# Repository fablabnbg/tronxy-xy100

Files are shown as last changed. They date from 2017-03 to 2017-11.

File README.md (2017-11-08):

# TRONXY-xy100 STARTT
Working with an inexpensive 3D printer. Other names: STARTT (by imakr.com) -- An almost identical but larger version is ANET A8.

The designs found here are also published at http://www.thingiverse.com/thing:2174029

External references:
* https://www.facebook.com/groups/officialSTARTT3dprintergroup/
* https://www.imakr.com/eu/en/forum/topic/108-custom-made-cura-for-startt-updated-24-july-2017#post-655
* https://github.com/prusa3d/Original-Prusa-i3/tree/MK2/Printed-Parts/scad
* https://www.imakr.com/en/content/169-startt-3d-printer-support
* http://www.ebay.de/itm/MINI-Tronxy-3d-DIY-Printer-Precision-Reprap-Prusa-8GB-SD-Card-120-140-130mm/192107538708
* http://www.gearbest.com/3d-printers-3d-printer-kits/pp_361425.html
* https://github.com/erikkallen/Marlin_tronxy
* http://www.thingiverse.com/thing:1683070 Anet A8 Improved X-belt Tensioner
* https://www.thingiverse.com/thing:2267392 TronXY XY-100 Startt iMakr - Fan Shroud Duct
* https://www.imakr.com/eu/en/forum/topic/32-startt-why-no-topics-or-usa-forums/page-2#post-65

Electronics:

MKS MELZI control board V5_2.0

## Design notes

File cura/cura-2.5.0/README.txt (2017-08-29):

Cura 2.5.0 loads the settings from cura 2.4.0 hooray.

But they introduced a new issue: Starting cura with stl files on the command
line only works when a full path is given. See the cura.sh script for a
workaround.

The x-endstop is defined to be at -10mm in the Firmware.
With the larger bed, we can gain another 10mm in x, by redefining it to be at 0mm

; directly after xy home, do:
G92 X0

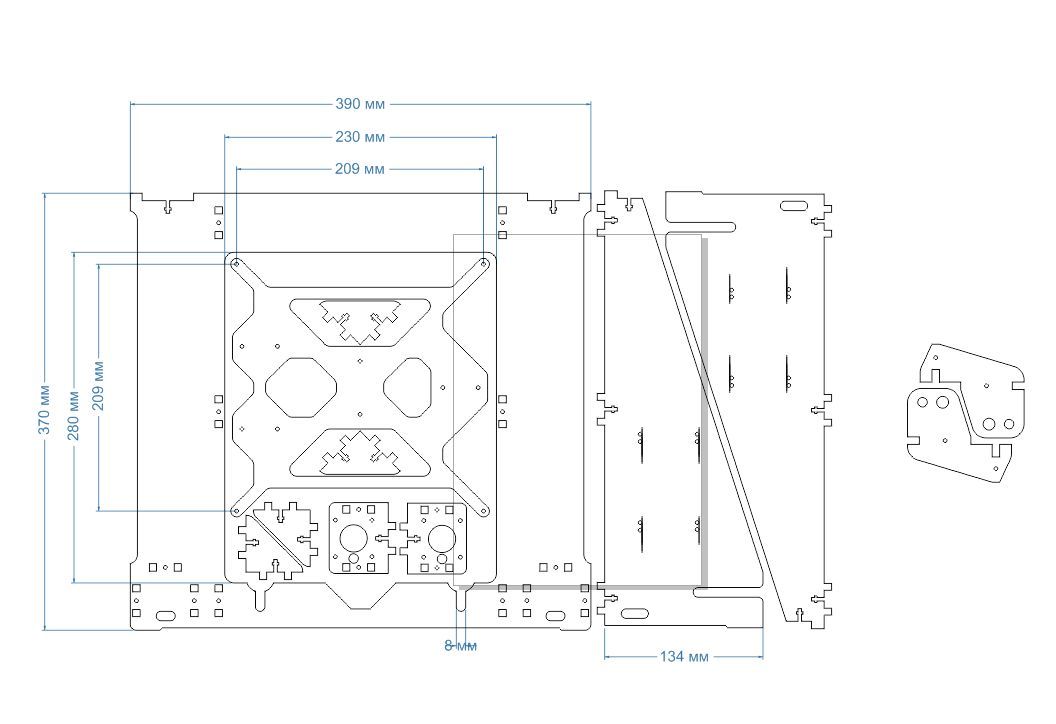
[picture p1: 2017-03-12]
doc/frame-drawing-s-l1600.jpg

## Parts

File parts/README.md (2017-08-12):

parts found elsewhere
=====================

* X-axis idler with belt tensioning http://www.thingiverse.com/thing:2205270
* TronXY XY-100 Startt iMakr - Fan Shroud Duct https://www.thingiverse.com/thing:2267392

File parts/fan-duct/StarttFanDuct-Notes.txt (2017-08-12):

TronXY XY-100 and iMakr Startt - Fan Shroud and Duct
Created On: 2017-04-23
Created By: Mark Dickson

This part is licensed under the Creative Commons - Attribution - Non-Commercial - Share-Alike (CC BY-NC-SA) license.  
You may do whatever you want with this file and design for your own personal use, but I drafted this up for the hobbyist community and wish to keep it "open-source."  
If you remix and re-release any part of this file, please ensure it is licensed under the same conditions.

This part is also available on Thingiverse here: https://www.thingiverse.com/thing:2267392

Description from Thingiverse:
2017-04-24 - Ran the part through NetFabb to fix some minor issues.

For those of you making the Startt printer from iMakr or the TronXY XY-100, you probably found that the 3D printed parts that came with your kit were not printed with the most care. Some other people have designed and posted various replacement parts that you can print yourself, but no one seemed to have posted the fan shroud, even though it was requested in the forums.

So here is my version of the fan shroud that came with my Startt kit from iMakr.

You can also find a number of redesigned parts here:
https://www.thingiverse.com/thing:2174029/

In addition to the Left and Right side X-Axis Gantry ends available here:
https://www.imakr.com/us/en/forum/topic/42-startt-3d-printed-part-files

If you have any feedback or suggestions, please let me know.

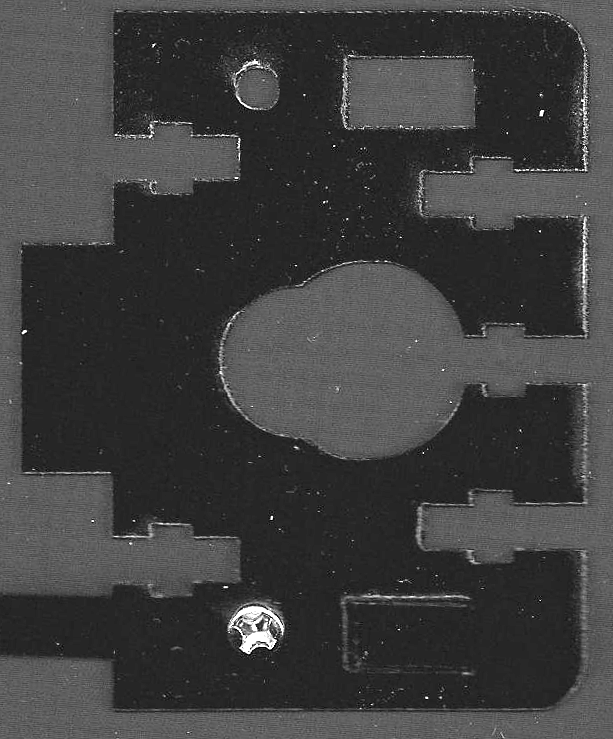
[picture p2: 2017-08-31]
parts/orig/scan300dpi/png/startt0008.png

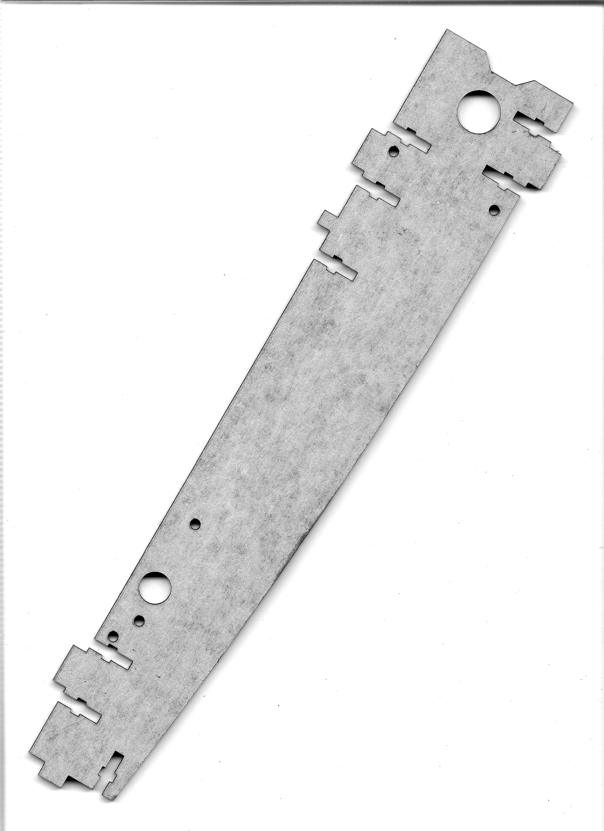
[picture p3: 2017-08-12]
parts/orig/scan300dpi/png/startt0002.png

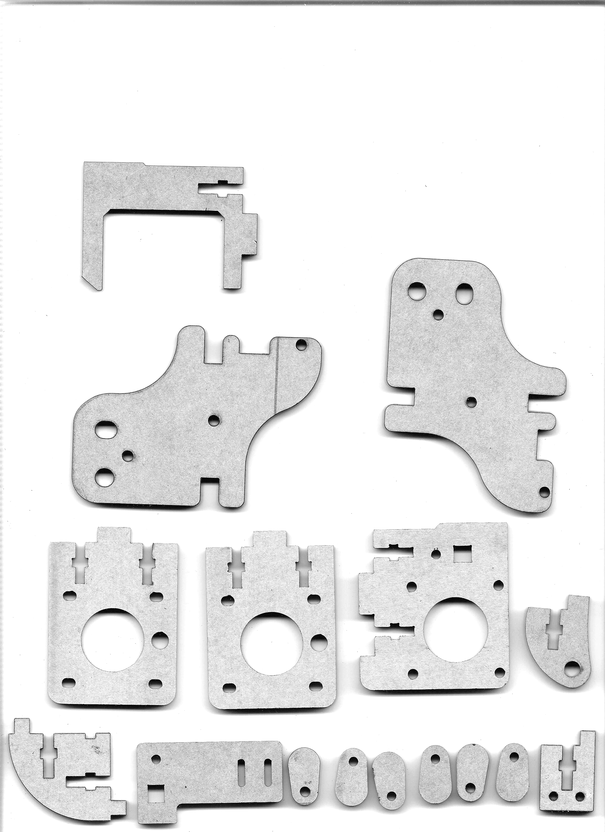
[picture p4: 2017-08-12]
parts/orig/scan300dpi/png/startt0004.png

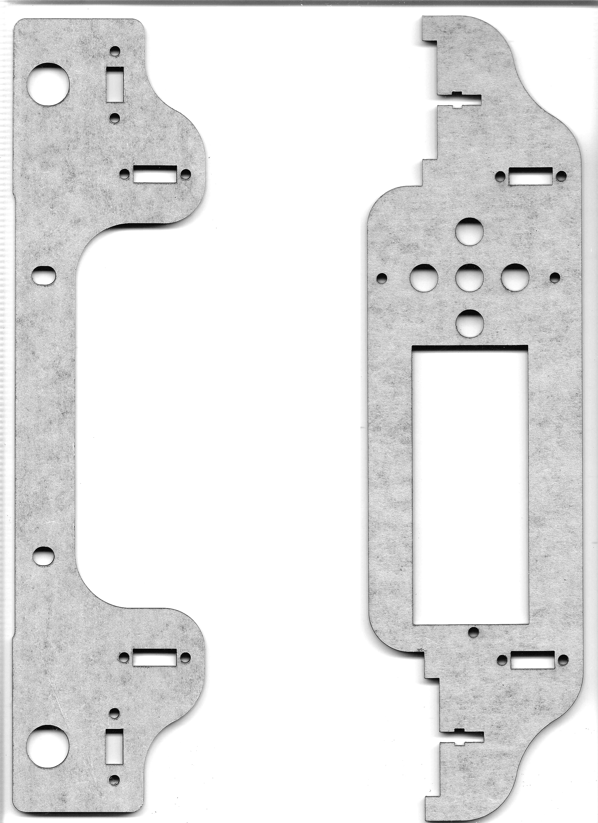
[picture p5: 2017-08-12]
parts/orig/scan300dpi/png/startt0003.png

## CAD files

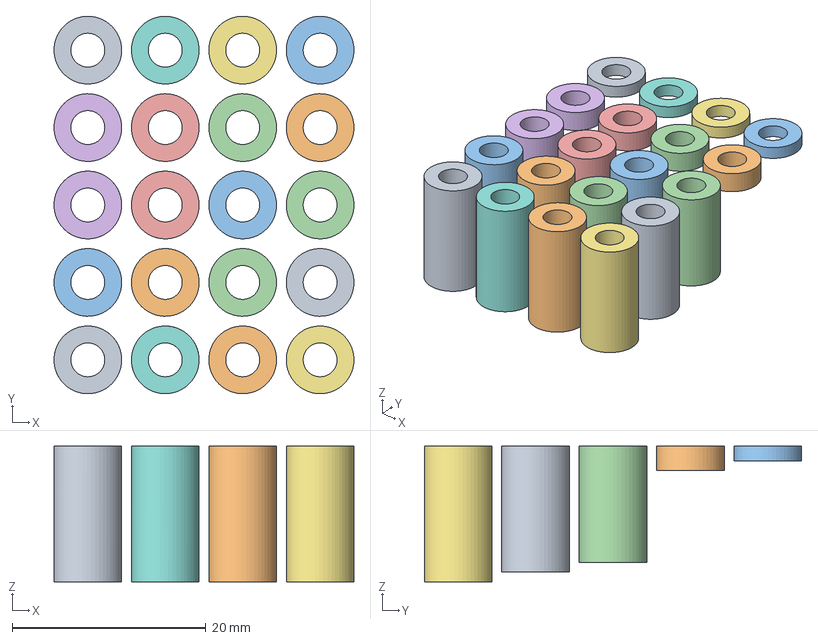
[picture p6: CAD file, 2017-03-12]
parts/display-spacer/display-spacer.fcstd
31.0 x 39.0 x 14.0 mm
13mm
13mm-4mm
13mm-4mm001
12mm
12mm-4mm
12mm-4mm001
14mm
14mm-4mm
14mm-4mm001
2.5mm
1.5mm
2.5mm001
2.5mm002
2.5mm003
1.5mm001
1.5mm002
1.5mm003
14mm001
12mm001
13mm001

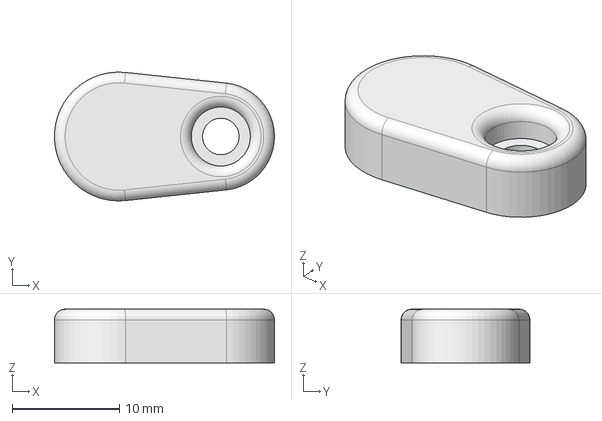
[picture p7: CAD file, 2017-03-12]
parts/end-cap/end-cap.fcstd
20.5 x 12.0 x 5.00 mm

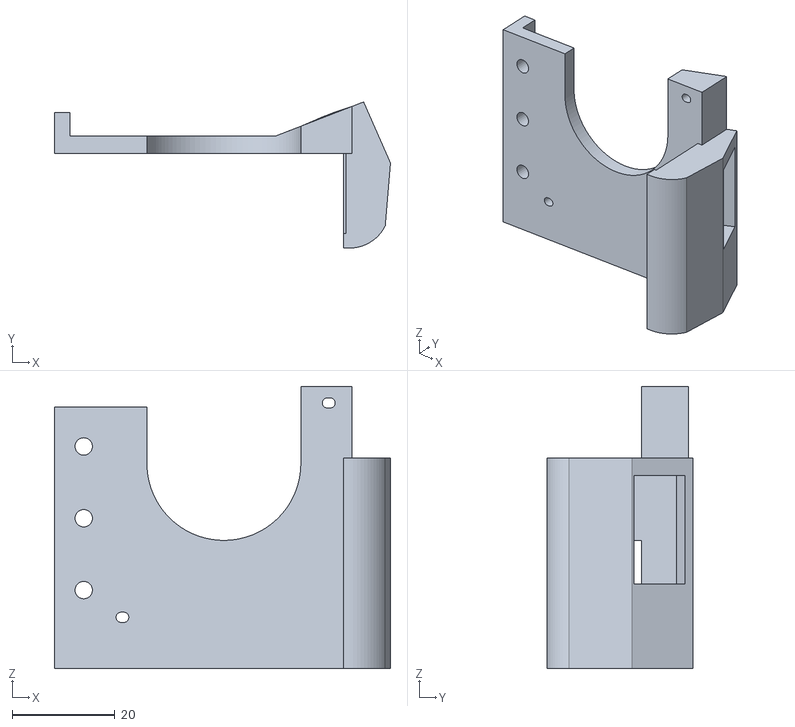
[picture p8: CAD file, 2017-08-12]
parts/fan-duct/StarttFanDuct.stl
65.5 x 28.5 x 55.0

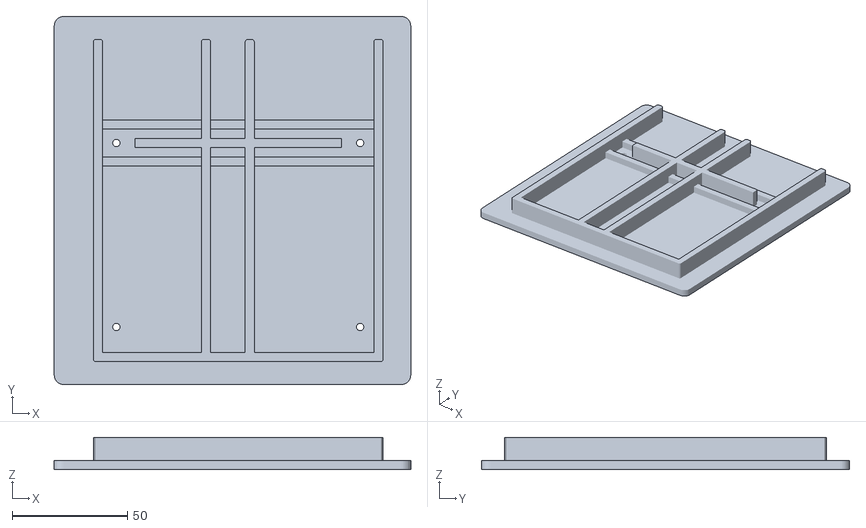
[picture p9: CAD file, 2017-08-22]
parts/plate/tronxy-plate-fc.stl
155.0 x 160.0 x 14.0

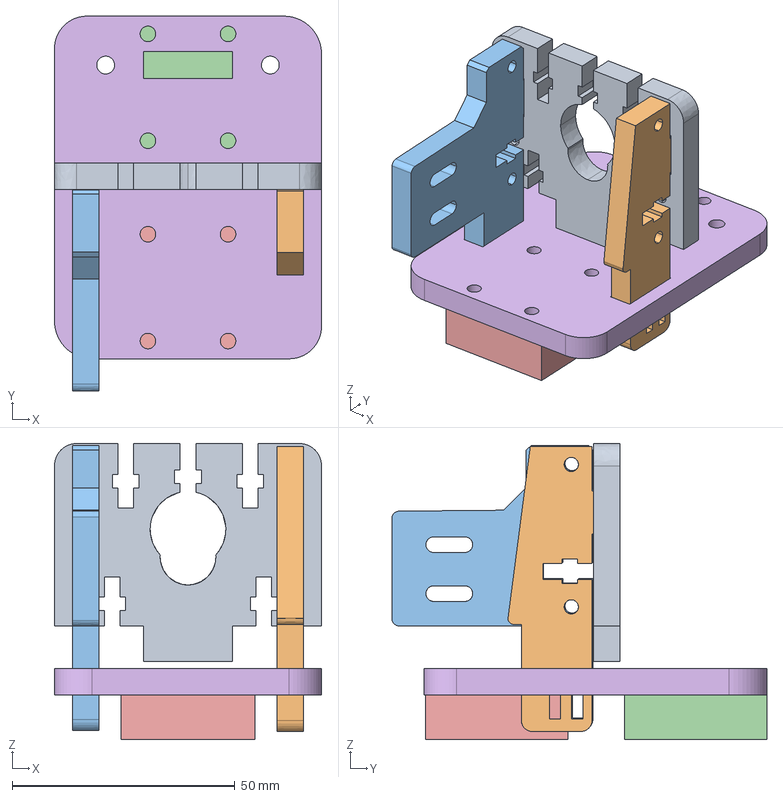
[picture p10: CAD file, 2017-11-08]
parts/print-head/head.fcstd
60.0 x 84.2 x 66.5 mm
top
left
right
bearingT
bearingB
Back

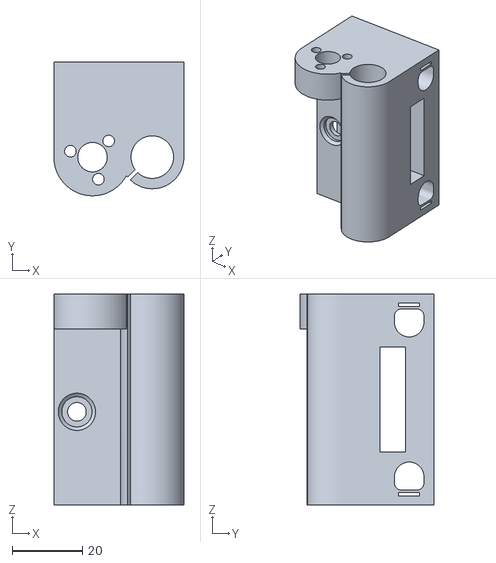
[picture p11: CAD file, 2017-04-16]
parts/Right.stl
36.9 x 38.0 x 60.0

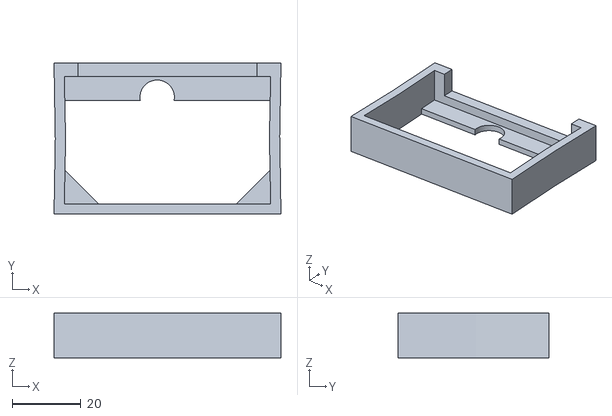
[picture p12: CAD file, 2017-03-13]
parts/x-gantry-far-end-cover/x-gantry-far-end-cover.stl
66.0 x 44.0 x 13.0

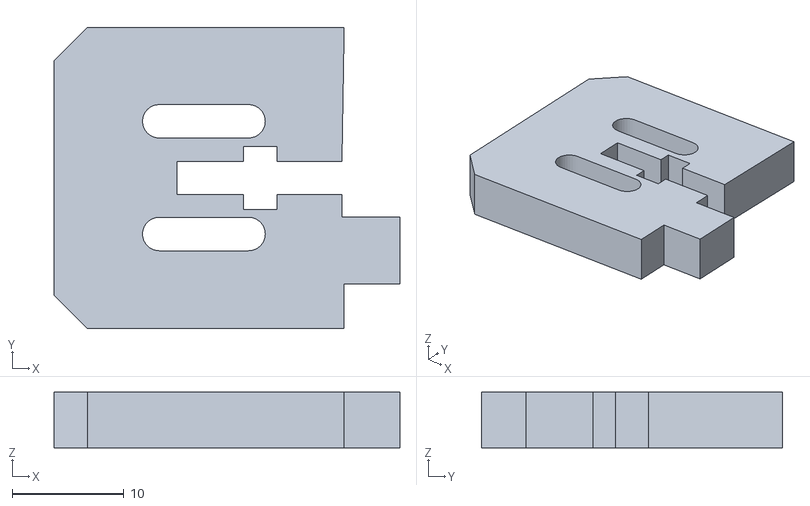
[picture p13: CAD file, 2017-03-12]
parts/y-endstop-mount/y-endstop-mount.stl
31.0 x 27.0 x 5.00

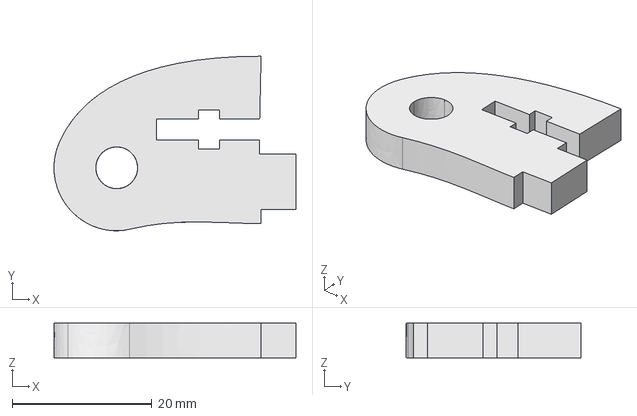
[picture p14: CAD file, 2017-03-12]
parts/y-idler-mount/y-idler-mount.fcstd
34.7 x 25.0 x 5.00 mm

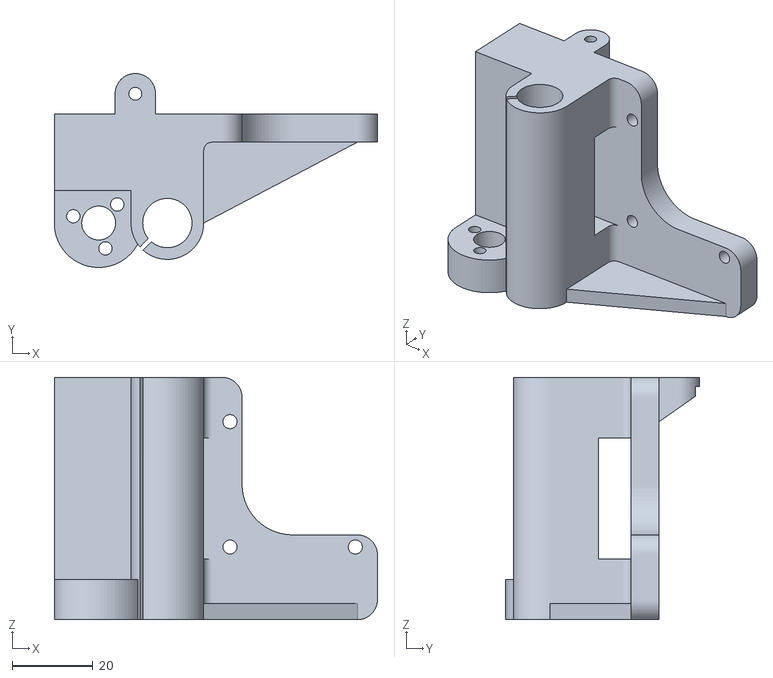
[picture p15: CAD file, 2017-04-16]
parts/Left.stl
79.9 x 48.0 x 60.0

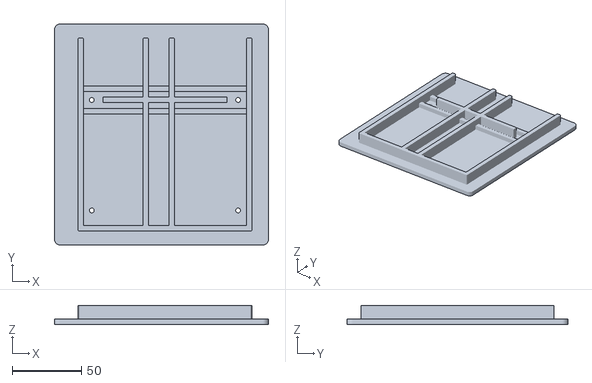
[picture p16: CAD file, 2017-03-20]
parts/plate/tronxy-plate.stl
155.0 x 160.0 x 14.0

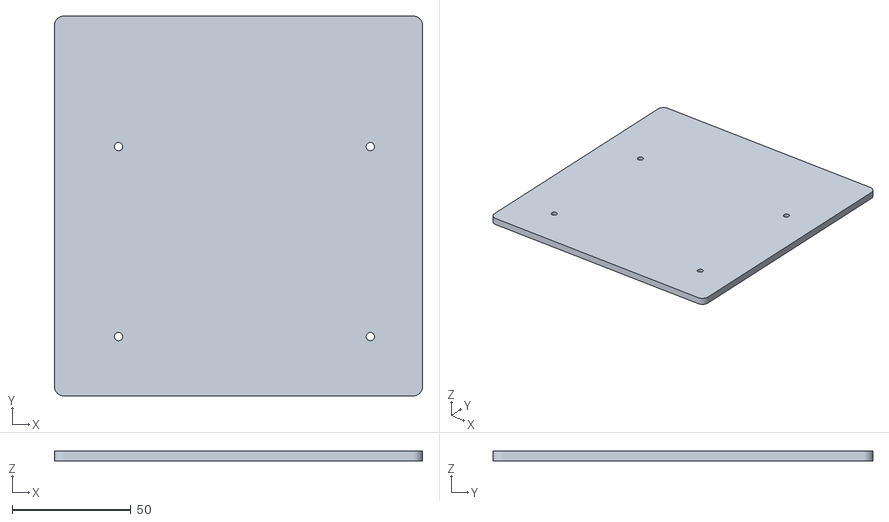
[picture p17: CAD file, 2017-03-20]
parts/plate/tronxy-plate_2.stl
155.0 x 160.0 x 4.00

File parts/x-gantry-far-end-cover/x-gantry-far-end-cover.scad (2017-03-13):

// Module names are of the form poly_<inkscape-path-id>().  As a result,
// you can associate a polygon in this OpenSCAD program with the corresponding
// SVG element in the Inkscape document by looking for the XML element with
// the attribute id="inkscape-path-id".

// fudge value is used to ensure that subtracted solids are a tad taller
// in the z dimension than the polygon being subtracted from.  This helps
// keep the resulting .stl file manifold.
fudge = 0.1;

module poly_rect4149_5mm(h)
{
  scale([25.4/90, -25.4/90, 1]) union()
  {
    linear_extrude(height=h)
      polygon([[-102.756266,-77.952540],[99.212247,-77.952540],[99.212247,-63.779312],[-102.756266,-63.779312]]);
  }
}

module poly_path4143_13mm(h)
{
  scale([25.4/90, -25.4/90, 1]) union()
  {
    linear_extrude(height=h)
      polygon([[-116.928714,-77.951426],[-115.619021,0.247187],[-116.928714,77.952540],[116.928714,77.952540],[115.619024,-2.372193],[116.928714,-77.951426],[92.125983,-77.951426],[92.125983,-63.779546],[106.297854,-63.779546],[104.988164,-1.389933],[106.297854,67.323629],[-106.299808,67.323629],[-104.990115,0.902037],[-106.299808,-63.779546],[-92.125979,-63.779546],[-92.125979,-77.951426]]);
  }
}

module poly_rect3338_2mm(h)
{
  scale([25.4/90, -25.4/90, 1]) union()
  {
    linear_extrude(height=h)
      polygon([[-113.385407,-77.951426],[-113.385407,-38.976815],[-106.299808,-38.976815],[-27.969722,-38.976815],[-28.247493,-40.738797],[-28.346682,-42.519785],[-28.255237,-44.331237],[-27.986785,-46.090362],[-27.550230,-47.788255],[-26.954480,-49.416010],[-26.208438,-50.964722],[-25.321012,-52.425483],[-24.301108,-53.789389],[-23.157630,-55.047534],[-21.899485,-56.191012],[-20.535579,-57.210917],[-19.074818,-58.098342],[-17.526106,-58.844384],[-15.898351,-59.440134],[-14.200458,-59.876689],[-12.441333,-60.145141],[-10.629881,-60.236586],[-8.818429,-60.145141],[-7.059304,-59.876689],[-5.361411,-59.440134],[-3.733655,-58.844384],[-2.184944,-58.098342],[-0.724183,-57.210917],[0.639724,-56.191012],[1.897868,-55.047534],[3.041346,-53.789389],[4.061251,-52.425483],[4.948676,-50.964722],[5.694718,-49.416010],[6.290468,-47.788255],[6.727023,-46.090362],[6.995475,-44.331237],[7.086920,-42.519785],[6.996476,-40.739247],[6.727540,-38.976815],[106.299814,-38.976815],[113.385404,-38.976815],[113.385404,-77.951426]]);
    linear_extrude(height=h)
      polygon([[-113.385407,31.889698],[-113.385407,74.409229],[-70.865874,74.409229],[-70.865874,67.323629],[-106.299808,31.889698]]);
    linear_extrude(height=h)
      polygon([[106.299814,31.889698],[70.865872,67.323629],[70.865872,74.409229],[113.385404,74.409229],[113.385404,31.889698]]);
  }
}

module yendstopmount(h)
{

poly_rect4149_5mm(5);
poly_path4143_13mm(13);
poly_rect3338_2mm(2);
}

yendstopmount(5);

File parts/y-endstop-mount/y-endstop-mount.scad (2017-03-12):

// Module names are of the form poly_<inkscape-path-id>().  As a result,
// you can associate a polygon in this OpenSCAD program with the corresponding
// SVG element in the Inkscape document by looking for the XML element with
// the attribute id="inkscape-path-id".

// fudge value is used to ensure that subtracted solids are a tad taller
// in the z dimension than the polygon being subtracted from.  This helps
// keep the resulting .stl file manifold.
fudge = 0.1;

module poly_yendstopmount_5mm(h)
{
  scale([25.4/90, -25.4/90, 1]) union()
  {
    difference()
    {
       linear_extrude(height=h)
         polygon([[-44.292335,-47.834962],[-54.921241,-37.204101],[-54.921241,37.204101],[-44.292335,47.834962],[37.204440,47.834962],[37.204440,33.661141],[54.921241,33.661141],[54.921241,12.401370],[36.495450,12.401370],[36.495450,5.315430],[15.944670,5.315430],[15.944670,9.920900],[5.313809,9.920900],[5.313809,5.315430],[-15.945952,5.315430],[-15.945952,-5.315430],[5.313809,-5.315430],[5.313809,-9.920900],[15.944670,-9.920900],[15.944670,-5.315430],[36.495450,-5.315430],[37.204440,-47.834962]]);
       translate([0, 0, -fudge])
         linear_extrude(height=h+2*fudge)
           polygon([[-21.506502,-23.317711],[-21.504502,-23.317711],[6.841209,-23.317711],[7.912337,-23.209753],[8.909951,-22.900120],[9.812692,-22.410170],[10.599198,-21.761263],[11.248109,-20.974759],[11.738063,-20.072015],[12.047700,-19.074393],[12.155659,-18.003251],[12.047691,-16.933625],[11.738031,-15.939664],[11.248048,-15.041438],[10.599112,-14.259017],[9.812591,-13.612472],[8.909854,-13.121874],[7.912271,-12.807293],[6.841209,-12.688800],[-21.504502,-12.688800],[-21.506502,-12.688800],[-22.577369,-12.797074],[-23.574862,-13.106913],[-24.477587,-13.596967],[-25.264152,-14.245888],[-25.913164,-15.032326],[-26.403230,-15.934932],[-26.712958,-16.932357],[-26.820954,-18.003251],[-26.712958,-19.074160],[-26.403230,-20.071592],[-25.913164,-20.974201],[-25.264152,-21.760637],[-24.477587,-22.409554],[-23.574862,-22.899604],[-22.577369,-23.209439],[-21.506502,-23.317711]]);
       translate([0, 0, -fudge])
         linear_extrude(height=h+2*fudge)
           polygon([[-21.506502,12.468730],[-21.504502,12.468730],[6.841209,12.468730],[7.912337,12.576689],[8.909951,12.886325],[9.812692,13.376279],[10.599198,14.025188],[11.248109,14.811693],[11.738063,15.714434],[12.047700,16.712050],[12.155659,17.783181],[12.047700,18.854395],[11.738063,19.852232],[11.248109,20.755285],[10.599198,21.542148],[9.812692,22.191416],[8.909951,22.681681],[7.912337,22.991538],[6.841209,23.099581],[-21.504502,23.099581],[-21.506502,23.099581],[-22.577368,22.991224],[-23.574860,22.681165],[-24.477585,22.190800],[-25.264150,21.541522],[-25.913162,20.754727],[-26.403229,19.851808],[-26.712957,18.854162],[-26.820954,17.783181],[-26.712957,16.712272],[-26.403229,15.714839],[-25.913162,14.812231],[-25.264150,14.025796],[-24.477585,13.376880],[-23.574860,12.886832],[-22.577368,12.576999],[-21.506502,12.468730]]);
    }
  }
}

module yendstopmount(h)
{

poly_yendstopmount_5mm(5);
}

yendstopmount(5);

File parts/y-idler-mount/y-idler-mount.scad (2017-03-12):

// Module names are of the form poly_<inkscape-path-id>().  As a result,
// you can associate a polygon in this OpenSCAD program with the corresponding
// SVG element in the Inkscape document by looking for the XML element with
// the attribute id="inkscape-path-id".

// fudge value is used to ensure that subtracted solids are a tad taller
// in the z dimension than the polygon being subtracted from.  This helps
// keep the resulting .stl file manifold.
fudge = 0.1;

module poly_path4149(h)
{
  scale([25.4/90, -25.4/90, 1]) union()
  {
    difference()
    {
       linear_extrude(height=h)
         polygon([[-14.980675,9.170943],[-14.125093,10.087945],[-13.164453,10.872662],[-12.115798,11.516096],[-10.996169,12.009246],[-9.822610,12.343113],[-8.612164,12.508700],[-7.381873,12.497006],[-6.148779,12.299033],[-3.555842,11.771471],[-1.130938,11.448630],[3.365558,11.251439],[12.000853,11.491303],[12.000853,9.491303],[17.000852,9.491303],[17.000852,1.491303],[12.000853,1.491303],[12.000853,-0.508697],[6.000853,-0.508697],[6.000853,0.491303],[3.000853,0.491303],[3.000853,-0.508697],[-1.999148,-0.508697],[-1.999148,-3.508697],[3.000853,-3.508697],[3.000853,-4.508697],[6.000853,-4.508697],[6.000853,-3.508697],[12.000853,-3.508697],[12.000853,-12.508700],[6.039284,-12.279476],[0.871483,-11.612112],[-3.552188,-10.537067],[-7.281372,-9.084800],[-8.901043,-8.226728],[-10.365707,-7.285772],[-11.681570,-6.265741],[-12.854835,-5.170443],[-14.798396,-2.769271],[-16.246030,-0.112717],[-16.667302,1.064963],[-16.918087,2.272144],[-17.000852,3.491613],[-16.918062,4.706162],[-16.672183,5.898579],[-16.265682,7.051656],[-15.701024,8.148180],[-14.980675,9.170943]]);
       translate([0, 0, -fudge])
         linear_extrude(height=h+2*fudge)
           polygon([[-5.499148,3.491303],[-5.695610,4.464415],[-6.231381,5.259069],[-7.026035,5.794840],[-7.999148,5.991303],[-8.972261,5.794840],[-9.766915,5.259069],[-10.302686,4.464415],[-10.499148,3.491303],[-10.302686,2.518191],[-9.766915,1.723537],[-8.972261,1.187766],[-7.999148,0.991303],[-7.026035,1.187766],[-6.231381,1.723537],[-5.695610,2.518191],[-5.499148,3.491303]]);
    }
  }
}

poly_path4149(5);

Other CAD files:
parts/plate/plate.fcstd
parts/display-spacer/display-spacer.stl
parts/end-cap/end-cap.stl
parts/fan-duct/StarttFanDuct.skp
parts/y-idler-mount/y-idler-mount.stl

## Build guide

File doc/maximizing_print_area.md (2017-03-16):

Maximizing the Print Area
=========================

The movement in X and Y direction does not exactly bring the nozzle to the edges of the print plate.
The movement in Z direction is limited.

To address this, several parts were redesigned. Most part are 2D objects to be cut out of 5mm acrylic or to be 3D-printed. These parts are constructed with inkscape and are contained in parts/parts.svg -- exported *.scad and *.stl files from these parts are found in corresponding subdirectories.
Other parts (e.g. end-caps) are created as true 3D-objects with freeCAD. Their source are *.fcstd files located in subdirectories of the parts folder.

With the modfications described here, the print area can be extended from 120mm x 140mm to 155mm x 160mm

Optimizing build height
-----------------------
1. The build plate can be lowered to ca 7mm above the Y-table. Adjustable by 
tightening the 4 thumb screws under the table. The available Z-end stop 
adjustment can compensate for that.

2. Upper movement is blocked by the print head hitting the buttons of the display already at a height of 65mm. We re-mount the display, so that the buttons protrude only 1mm through the top plate, and the display itself is flush. parts/display-spacer.stl has a range of spacers, long and short in some variation.

3. The remaining obstacles are
* Two rounded acrylic pieces colliding 5mm before the brass nuts would hit the top cover.
* The mount of the print head wastes ca 20mm height. The nozzle height should not be much lower than the linear bearings.

Optimizing the front edge
-------------------------
In Y direction, the plate cannot move far enough inwards, so that the nozzle
reaches the front edge.

There are several obstacles, that prevent sufficient movement.

1. The Y endstop mount is not adjustable. It stops the movement early.
A redesigned y-endstop-mount.stl allows adjustment.

2. The long 20mm screws from the end-caps of the rods protrude ca 10mm beyond the nuts. This collides with the table.
Redsigned end-caps with only 2mm thickness under the screw head allow for use of 10mm screws that do not protrude at all.
  
3. The Y motor mount has an upper corner that collides with the table.
The corner needs to be cut away with saw and file. (I am too lazy to recreate that piece right now.)

4. The y motor connector is on the top according to the assembly guide. This collides with the print plate. Rotate the motor 180 deg, there is enough space on the bottom to accomodate connector and cable.

With these adjustments, the nozzle reaches the fromt of the build plate just
before the table hits the screws in the back wall. No further optimization
possible there. Please make sure all cables are zip tied away from the
collision area.

Optimizing the rear edge
------------------------

The programmed travel is longer than the physical travel. Pausing a print causes the table to move fully outward and hitting the physical limits. The y-position is lost, resuming the print is not possible.

1. When the table moves forward it collides with the large washers of the idler.
A redesigned parts/y-idler-mount lowers the idler by 1.5mm so that it fits 
under the table. A belt tensioning mechanism could also be added here. Easiest is an oblong hole for mounting the roller bearing.

The belt is attached to the table at a position reached by the idler. This prevents further movement. The rails have 8 mm more travel, but the nozzle is already 4 mm beyond the rear edge of the plate.

Optimizing left edge
--------------------

The x-limit switch protrudes from the print head. The switch should trigger just 1mm before the print head hits the block.

Optimizing the right edge
-------------------------

There is ca 20mm unused travel on the right hand side. We need smaller roller bearings for the x-idler, so that the belt moves more horizontal. It should have approximately the same diameter as the pulley. 
The programmed travel is shorter than the physical travel.

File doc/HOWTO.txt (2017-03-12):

					jw, Sa 11. Mär 13:36:00 CET 2017
					jw, Fr 10. Mär 20:47:28 CET 2017
do the assembly
===============
firefox https://www.imakr.com/en/content/169-startt-3d-printer-support
# open Assembling_Guide_English.pdf
#
# Additional resources:
# - Reserve table space of ca. 0.8m x 1.4m
# - Have a plate for spreading out the contents of the pack of screws and nuts. 
# - Have a second small plate for collecting the screws and nuts for each step.
# - A tipped knive, safer if blunt.
# - pointed pair of pliers for holding nuts. Especially also the ring on the power jack.

-> The acrylic parts are all covered on both sides with adhesive paper.
   This needs to be peeled off. A tipped knive is very helpful to get moving at one corner.
   The small flat screwdriver also works.
 
-> Step 2: There are two switches with short leads, one with long leads. Used a short one.

-> Step 4: There may be some acrylic dirt attached to the inside of the Motor
   Holder. Scrape this off with a knive.
   Do not tighten the 'Motor Holder' without assembling the motor
   There should be a hole in the 'Motor Holder', so that the screw beneath can be reached.

-> Step 6: In Parts required: 'Smooth Rod x2' should say 'Smooth Rod (shortest) x2' 
   This is only mentioned later, causing a needless moment of confusion.
   
-> Step 7: Orient the motor connectors under the longer side of the acrylic pieces.

-> Step 8: In Parts Required: Left stepper motor should mention '(A)', right motor '(B)'

-> Step 9: Use the limit switch with the long leads.

-> Do step 13 before step 12. The power jack assembles much more easily while the back is separate.

-> Step 13: The threaded rods used here are longer than the lead screws. Their tracks are sharper, 
   but same pitch as those of the lead screws (not 'thinner'). 

-> Step 15: The wider side should be on the left, near the Z-limit switch.
   Expect the 3D printed spanner to be spent, after being used here.

-> Step 19: The thicker and longer rods are 28.5cm long.

-> Step 20: preassemble the lead screws into the bronce metal parts. 
   They might have a very tight initial fit. Remove again.
   The bronce metal parts might be mounted slanted. Loosen their screws.

-> Step 21: There is nothing that holds against the force of the X-belt. Ouch.
   Rod caps on the printed part are missing!
   5) Feed back through the bottom gap of the ---acrylic--- +++3d printed+++ piece.

-> Step 22: The screws on the PCB cannot be tightened without bending the board. 
   Washers and spacers needed! The 3x 25mm screws need spacers too!
   The buttons must not protrude from the acrylic board more than 1mm, or they get hit by the printhead.
   The display must be flush with the acrylic board, or the bowden tube gets caught.

-> Step 23: The two holes in the acrylic side have bad tolerances. 
   The lower holes should go up by 1mm.
   The screen plate should be 2cm further back, so that the teflon tube can move freely in front.
   The teflon tube should be 10cm longer.

-> Step 25: no sunk space for screw head in bed.
   The long end of the bed points iwards.

-> Step 27: 'over the top' means over the top of the hot end, but below the display bridge.
   Fix the black wrapped cable trunk to the hot end with one of the white pieces, fix it to the frame 
   with another. 
   14. Take yourself time to really tidy up the cables.

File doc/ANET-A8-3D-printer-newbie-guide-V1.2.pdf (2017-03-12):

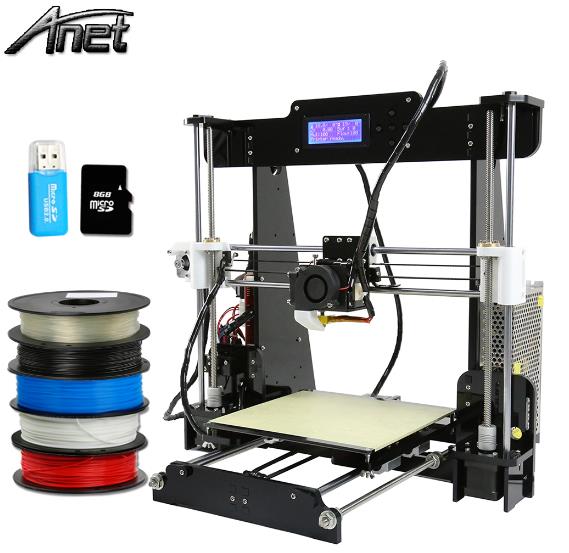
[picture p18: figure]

Anet A8 printer assembly guide for the newbie V0.1

# ANET A8 3D printer

# Additional build & usage

guide.

Kevin D Smith “3D printer hobbiest and quite a nice guy”

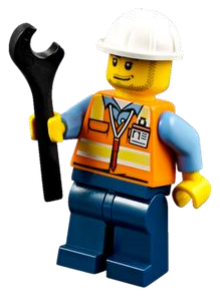
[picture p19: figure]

Anet A8 printer assembly guide for the newbie V0.1

Introduction.

So, you have just taken delivery of a large cardboard box from China containing multi layered parts to build a 3D printer and your thinking “Where do I start”, “Where are the instructions”, “will it work”.

DON’T PANIC………

What will this guide do for me?

It will provide you with an insight in how a 3D printer works, things to look for when building it which are not covered by the build guides and things to do to ensure the printer and you have a long and productive relationship.

What will this guide not do for me?

It won’t give you that Perfect printed object. The Anet series of printers like many things are massed produced and no two printers operate the same. However with time, learning how to tweak the printer and the associated 3D printing software you can work towards that perfect printed object

About me.

I have been involved in IT / Electronic engineering for the last 20+ years. After spending time in the Armed forces, I re-trained for a career in computer systems design but with Electronics still playing a role. I came across my first 3D printer around 6 months ago and after many hours of using Google (Other search engines are available) I opted for a semi built kit. It was great, 2 hours of self-assembly and I was up and running. I then thought how about building one from scratch, so I bought a Anet A8 clone and the rest is history as they say.

So enough of these ramblings, let’s get into the nuts and bolts and strange looking parts of your 3D printer.

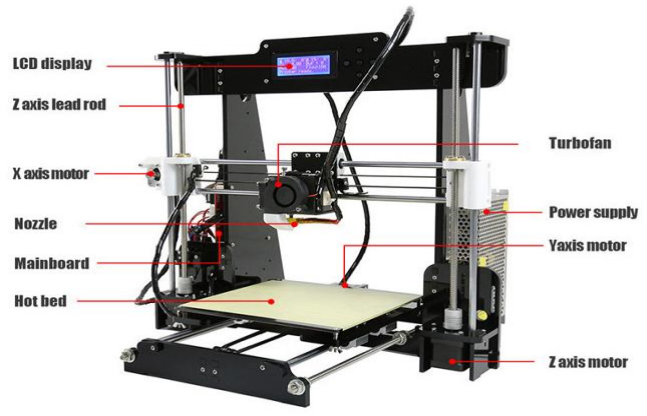
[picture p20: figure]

Anet A8 printer assembly guide for the newbie V0.1

Section 1 - Anatomy of the A8 3D printer

The diagram above shows the key parts of a typical 3D printer, lets understand better what these things do.

1. LCD Display – This is where key information about you printer is shown, this included things like Tempature settings for the Printer head and Bed, access to files stored on the SD card, fine tuning of settings for the X, Y and Z axis motors etc.
2. Z axis lead rod – These are use to lead or drive a component such as the Z-Axis assembly on a printer.
3. X-Axis motor – This motor/belt controls the X-axis travel and the head movement from left to right.
4. Nozzel – This is where your filament appears once it has been heated upto the required tempature, most printers are fittem with a 0.4mm nozzel as standard
5. Mainboard – This is the brains of the operation base on a Ardunio processor it also contains the electronics for the motors, heater elements, USB port for connections to a computer etc.
6. Hotbed – This is where the filament and your printer object is printed onto, typical operation temparatures are in the region of 40-60c

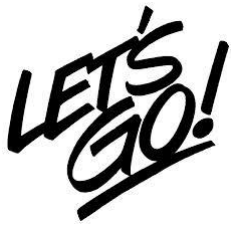
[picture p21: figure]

Anet A8 printer assembly guide for the newbie V0.1

7. Turbo Fan – this provides a controlled airflow to the object being printed ensuring it cools down correctly avoid you having a large pool of PLA or ABS sitting on the heatbed.
8. Power supply – All the electronics need power, so this is what this unit does, typical designs provide either 12 or 24V DC at around 20A
9. Y – Axis motor – this controls the hot bed movement during a print using a single motor and belt.
10. Z – Axis motor – This controls the up and down movement of the Head using two motors connected to the Z-Axis linear rods which in turn are connected to the X-axis left and right drive assembly.

In the next section, we will start getting into the build areas which are not covered by the instructions.

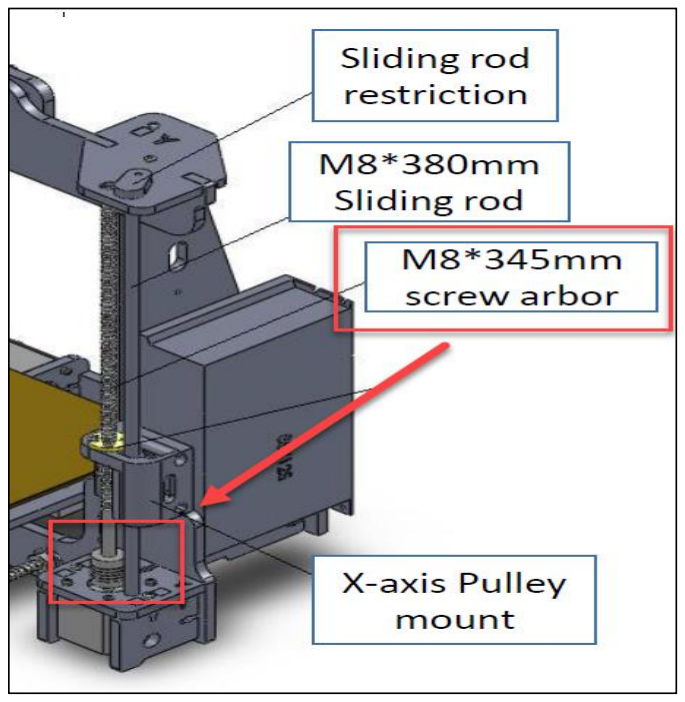
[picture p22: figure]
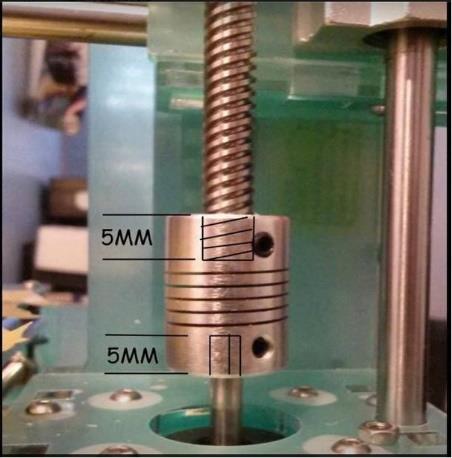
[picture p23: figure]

Anet A8 printer assembly guide for the newbie V0.1

## Section 2 - Part 1. – Mechanical

Z-Axis Linear rods and Couplers.

The Z-Axis consists of a number of components which need to assembled correctly. The picture below shows the parts we need to focus on (highlighted in the red boxes).

Z-Axis Motors and Linear Rod.

When you remove the Z-Axis motors from the packaging, the Z-couplers will either be installed on the motors or in a small packet. The first thing to do is ensure the Z-couplers are installed a distance of 5mm onto the Z-Axis motor shafts and then during the assemply of the Z-Axis motors and the X-Axsis mounts ensure the Linear rods (Screw arbor) are inserted 5mm into the top of the Couplers. The Z-Coupler has 4 small grub screws which need to be tighted once installed onto the motor and Linear rods (see photo below).

Next Section - Electrical checks

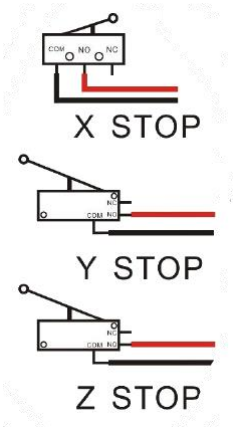
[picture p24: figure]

Anet A8 printer assembly guide for the newbie V0.1

Section 2 – Part 2 – Electrical

This section is broken down into the following areas

- Micro-switches
- Power supply
- Cable management

Micro-Switches

There are a number of micro switches fitted to the printer which control the home positions for the X, Y and Z Axis. Each switch has to be wired correctly during the assembly of the printer. The picture below shows the correct wiring of these switches.

It is very important that you make sure the wiring to the switches is fully secure and the connectors going back to the motherboard are connected to the right sockets on the board. I have seen a number of people have problems with the Heat bed not homing correctly for example and it was down to the cabling not fitted correctly on the switch or the connector not fully homed on the motherboard.

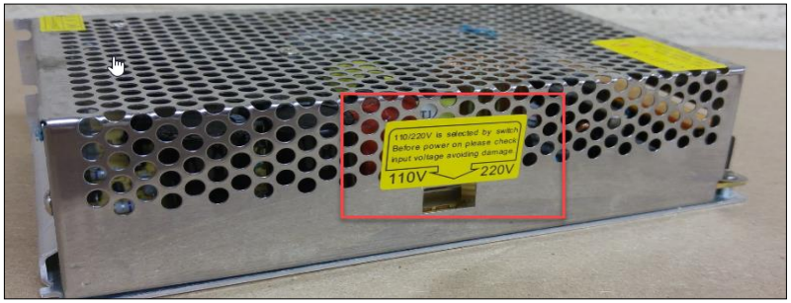
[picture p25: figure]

Anet A8 printer assembly guide for the newbie V0.1

Power supply.

This is one of my favourites and at the time of writing this document one of the most popular parts to fail, either wired incorrectly or great confusion in terms of installation.

The supplied unit is a 12V 20A switch mode PSU module. It have a number of electrical wiring connectors which are required during installation and more importantly a Voltage selector switch. (shown below)

Before you do anything with the electrical wiring on the printer, check the voltage selector switch as shown above. A lot of these PSU’s are being sent out with the selector switch set to 220V 50Hz (Slider switch set to the right). This is fine for those country which operate on this voltage. However the USA operates on 110V 60Hz. Now believe it or not, if you plug the PSU into a 110V supply on the 220V setting, I know what your thinking “Well its half the voltage here, no problem” – Wrong due to difference in the frequency of the AC Voltage (I won’t bore you with the science) you can still damanged components expecting to operating at 50Hz and not 60Hz. Now if it was set to 110V and plugged into a 240V sockets the effects can be a bit more lounder and colourful and you will kill it .

So please make sure the Switch is set correctly according to your country.

AC Mains Wiring colours

The mains colouring wire varies from country to country, so please make sure you wire the PSU correctly according to your country via this link (http://inspectapedia.com/electric/Wiring_Colours.php) or refer to the table below

USA | Phase | UK (Europe)
Red/Black | Live | Brown
White | Neutral | Blue
Green | Earth | Green

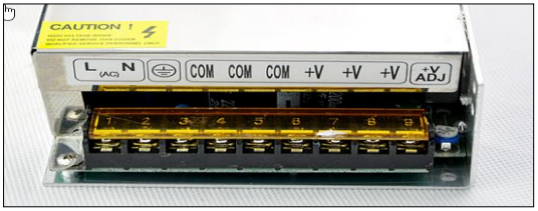
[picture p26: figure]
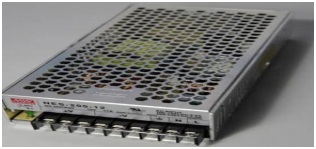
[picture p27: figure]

Anet A8 printer assembly guide for the newbie V0.1

DC voltage wiring

The power supply comes with a total of 3 pairs of connections each delivering 12V DC

The connections are either marked +V and Com or +V and -V as shown below

In both cases V+ = 12V positive and in the case of -V / Com this is the negative (ground)

Please make sure you wire up the power cable provided correctly and if possible secure into the connectors with suitable crimp connectors such as these. (Spade connectors)

In terms of the power cable it can be provided in two flavours

Solid Red and Solid Black = Red = +V and Black = -V / Com.

Solid Red and Solid Red with a black streak = Red = +V and Red/Black streak = -V/Com.

Again check the cabling before you wire it up to the main board etc.

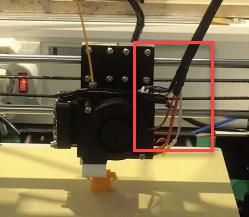
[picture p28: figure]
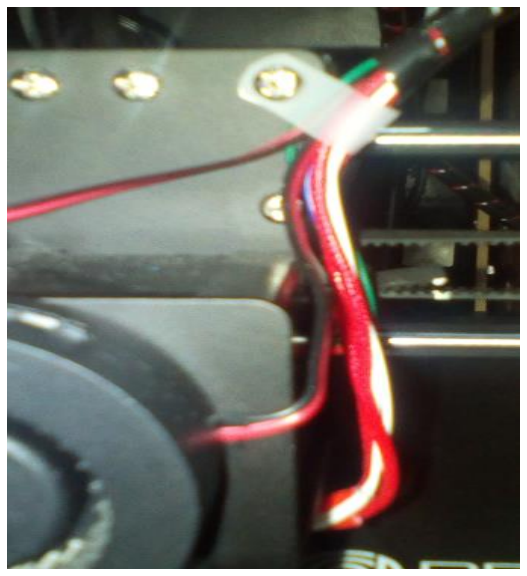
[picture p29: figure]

Anet A8 printer assembly guide for the newbie V0.1

Printer Head Cable Management.

One of the most popular photos on completed printers I see is the one shown below.

The installation guide does not tell you about how these cables should be secured and this can lead a to the printer failing if the heater elements getting snagged. In some cases this may lead to a complete burn out of the the printer head assembly, if they come out.

The printer Head cable harness once assembled should look something like this.

The white clips (supplied in the kit) are used to secure the cables going the to Printer head and fans from working loose or getting caught in the print head as it moves.

PLEASE make sure you carry out this step.

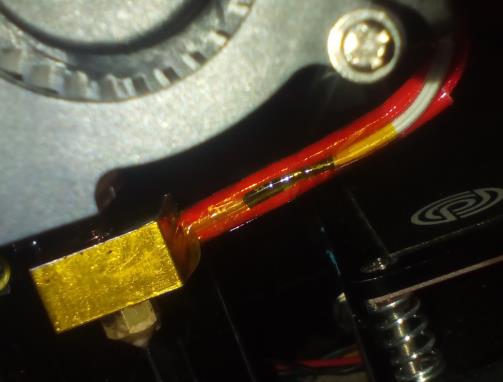
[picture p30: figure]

Anet A8 printer assembly guide for the newbie V0.1

There is a second part to this sectoin which is the most important bit. However it should be noted some of the printer heads being delivered pre-assembled as shown below so this may not apply to you.

In the photo shown above you will see the cables to the heater blocked sealed with Kapton Tape, this tape is ideal for use in areas of high temparture and in particular on 3D printers.

The cables going into the printer head consist of the heater element and the temparture sensor. These are normally secured with small grub screws so check these are tight and then the head is sealed with kapton tape along with part of the cable harness you secured earlier. If this has not been done, do so to ensure these components don’t come out during normal operation of the printer.

The other thing to check here while doing the above is the Printer nozzle, if this is not tight then you risk filament feeding back up the hole which the nozzle screws into and forming a nasty mess on top of the printer block, so check this is secure before fully fitting the head.

Next Section – Pre-flight checks and maintenance – but first a break

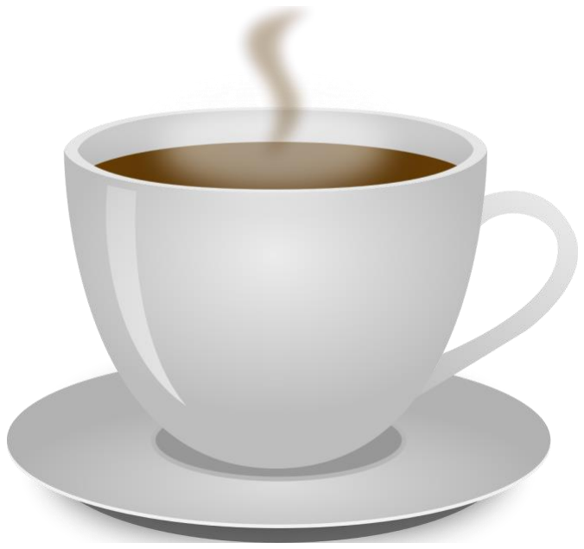
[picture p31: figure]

Anet A8 printer assembly guide for the newbie V0.1

# BREAK TIME

So, by now you’re maybe thinking wow that’s a lot of information, I bet. Well believe it or not you have managed to work through almost 90% of the known areas which I didn’t know about along with quite a few other people during the assembly of their 3D printer. If you have got this far then you are almost there. So, have a break, Tea or coffee and come back shortly to the final part of this guide.

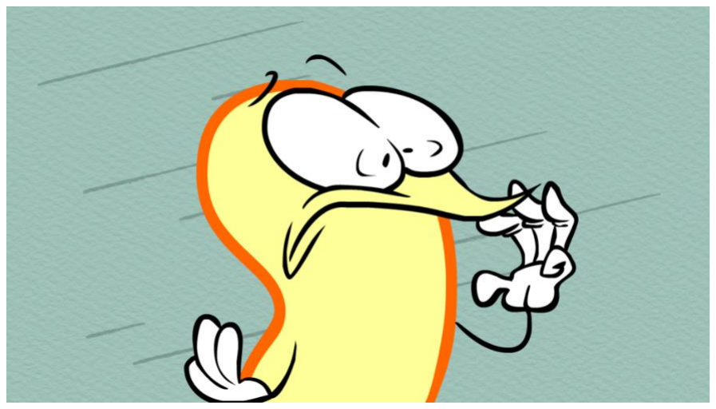
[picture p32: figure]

Anet A8 printer assembly guide for the newbie V0.1

Section 3 – Pre-flight checks and maintenance.

So, if you have got this far, your ready stand back and start printing your first 3D object.

Let’s double check a few things

1. Power supply voltage selector
2. Power supply cables wired in correctly
3. Printer head secure and Nozzle tight
4. Cables from Printer secure
5. All connectors secure and in the right places
6. Pizza and choice of liquid refreshment ready

## HOLD ON – Heat Bed levelling

Anet A8 printer assembly guide for the newbie V0.1

Yes, it’s moment every 3D printer owner loves or hates but it has to be done to make that first printed object look pretty good. So here is a basic guide for you to follow. I’m not going to say it’s perfect but it will at least give you a basic understanding of the process.

The process of levelling is fairly straightforward, and does not require any fancy tools. It involves only seven (7) easy steps:

1. Stiffen the print bed support screws.
2. Set adequate tension in the springs.
3. Adjust the Z-Axis.
4. Set the tolerance.
5. Level first diagonals.
6. Level second diagonals.
7. Secure hardware.

Important TIP note:

Ensure the hotbed has been brought up to temperature before proceeding and the stepper motors are disabled.

Stiffen the Print Bed

To stiffen the print bed, tighten the nuts under the bed so that the support screws are absolutely perpendicular to the print bed surface.
Set Spring Tension in the Springs

The springs most commonly used on 3D printers. While more than adequate for the job, they provide little resistance when fully extended, so they need to be compressed enough so that they provide sufficient support for the weight of the bed, while still allowing for slight compression during the occasional head crash, or low to the surface print (more on this below). We ultimately want to set the tension in all the springs, but for now, we only want to set them leaving the last spring relatively loose. It is not important that they be level at this point. It is generally easier to slightly over-tension the springs with the intent of loosing them off during the levelling process. This allows you to set the Z-Axis (in the next step) to just above the bed and the you will raise the print bed back up to the hot end during the levelling process.

Anet A8 printer assembly guide for the newbie V0.1

Adjusting the Z-Axis Home Position

As mentioned in the prerequisites, the Z-Axis min limit switch (Z-endstop) should be located on the same side as the X-Axis motor. The reason for this is that this side of the X-Axis weighs more, and is less likely to lag behind during downward movements like homing. Through repetition, bring the Z-Axis nozzle down to the surface of the print bed at the

centre. t does not have to be perfect, but should be within +/- 0.5 mm (but Ideally just above the bed), I prefer to be

a little above the surface. Approx 0.2mm
Tolerances

In addition to being level the distance between the hotend and the bed is important. If you are using a strongly flat bed, such as glass, you should be able to achieve a gap of 0.2 mm. For less flat surfaces your gap will need to be larger. A common method of setting the tolerance is to place a piece of paper onto the bed, so that you can still move the piece of paper, but there is a slight drag.

As you go around the bed, adjusting the level, you should use a piece of paper to check the tolerance.
Levelling Diagonal 1

The levelling order is Front-Left, Back-Right, Back-Left, Front-Right. We refer to the first pair as Diagonal 1. With the printer homed, disable the motors and position the head over the Front-Left corner of the print bed, use the tension wheels to adjust the height of the print bed. Using the piece of A4 paper between the bed and the nozzle adjust the height until the nozzle touches the paper but you can still pull the paper out with a little bit of drag. Re-home the Z-Axis and checking that the paper still drags. Adjust as needed until you can achieve drag without movement of the print bed.

Once you have set the front-left corner, repeat the process with the opposite diagonal corner in the back-right. Return to the front-left corner and verify that nothing has changed. On or two repetitions, may be required.
Levelling Diagonal 2

The second diagonal is levelled in the same manner as the first, but starting in the back-left corner, and ending with the front-right. It may be that after completing the procedure to this point, you find that Diagonal 1 is no longer set. It will most likely be a small adjustment, and a second repetition of the levelling process will correct this in most cases.

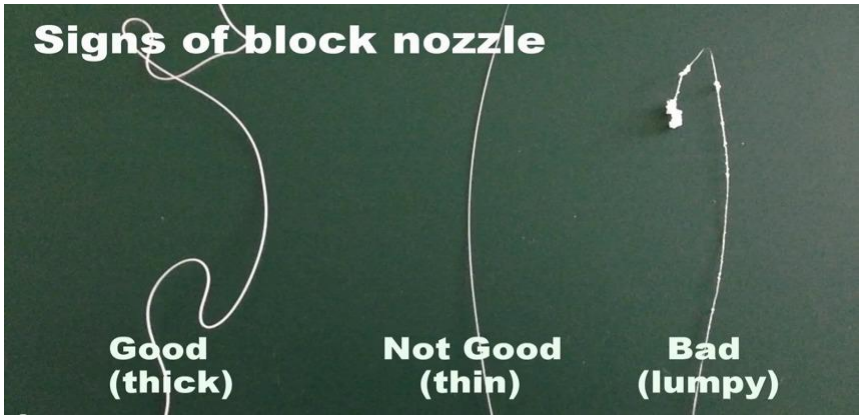
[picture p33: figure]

Anet A8 printer assembly guide for the newbie V0.1

Securing the hardware

One thing I cannot recommend enough, is that you secure the hardware. 3D printers are subject to high and low frequency vibrations, which will loosen any part, given sufficient time. A quick dab of hobby paint at the base of each nut will insure that your levelling effort pays off for the duration. You could use a second nut to lock each of the tensioning nuts, and then add a drop of red paint. It gets the job done, and is easy enough to remove with a hobby knife, if you need to take something apart.

3D Printer Maintenance

Like a Car, you printer consists of a number of precession made moving parts and parts that can get stressed under high temperature and wear and tear over time, here are just a few things to keep an eye on.

Many of you don't like the nozzle clogs and blocks. Even the smallest contamination can block the 0.4mm nozzle, you can use a 0.4mm or smaller drill bits to clean up the aperture while the hotend is hot. But sometime (many time) the contamination would come back and block the nozzle. That’s very bad especially when you are in the mid of big prints.

Anet A8 printer assembly guide for the newbie V0.1

Nozzle block or clogs can be identified via below symptoms,

- filament is not extruding uniformly
- extrude very thin filament than usual
- Or the filament is not at all coming out from nozzle.

From the above symptoms, we are sure that the nozzle needs clean up, here are some methods known to work

## Cold Pull-out Method

PLA filament can be used to remove hard to remove contamination completely out of your nozzle. PLA has a useful property that you can heat it to a temperature between its glass transition and its melting point where it becomes a rubbery solid. When you pull it backwards it stretches and becomes thinner, so it peels away from the walls of the melt chamber and comes out in one piece. Anything in the melt chamber is pulled out with it leaving it completely empty and clean.

Here is one method on how you clean the nozzle

1. Heat to extrusion temperature and pull out the filament being used .
2. Use a 0.4mm drill shank to clear the aperture.
3. Insert PLA filament (preferably natural so you can see the contamination) and flush through the remaining original filament. You may need to keep clearing the aperture with the drill shank.
4. Cool the extruder to 80°C with the drill shank in place to ensure the nozzle is clear.
5. Send M302 command to disable cold extrusion check
6. Remove the drill and then pull out the PLA.
7. Inspect the end that comes out to see the culprit contamination.
8. Send M302 command again to enable cold extrusion check

Of course, if you are using PLA you can just do steps 4 and 5. This method of cleaning with PLA is much better than using solvents or burning out nozzles that I often see recommended as it can be done in easily and doesn’t risk damaging anything.

Anet A8 printer assembly guide for the newbie V0.1

## Cleaning with flame torch and acetone

What you need:

- Acetone (This chemical don't like your skin, so weare glouse and protection glass)
- Torch (You can use your gas stove - be careful )
- Very thin wire
- Soak the removed nozzle into acetone for about 15 minutes to clean out exterior dirt. Use a tissue paper/cloth wipe clean the nozzle.
- Place a nozzle on a stone and burn it using the torch for about 1 min. Make sure it is extremely hot until you see slight changes in the colour.
- Use a very thin wire to clear the hole in the nozzle. If the wire cannot go through repeat step 2 again until the can go through. You do not want to scratch/damage the internal wall of the nozzle. Do not force through the hole with the wire. I use soft copper wire stripped from an unused phone cable.
- Monthly Maintenance
- Check your belt tension. The belts should be tight enough that they feel tight when pressing down on the midpoint of the belt run. Make sure that the axis movement is smooth and without binding.
- Wipe down the smooth rods. The bearings/bushings (ball bearing ones as standard) may need a little lubrication from time to time. If you upgrade to the IGUS bearings, these are self-lubricating. Wiping with a clean dry cloth is suggested in this case.
- Lightly lubricate and clean the threaded rods. Do not use anything petroleum based. Silicone based or lithium based grease is recommended. Clean the threaded rods by running the axis up and down while wiping the threads.
- Use compressed air to blow out the fans
- Quarterly Maintenance
- Check the set screws on the stepper motor pulleys and the small gear on the extruder, tighten if necessary. Use of a mild thread locking compound is acceptable.
- Examine the threaded rod couplers. Verify that any frame screws are tight.

Next Section – Hints, tips and conclusion.

Anet A8 printer assembly guide for the newbie V0.1

3D Hints and Tips.

Do not print with a badly calibrated printer! Some printers are even delivered while not properly tuned, and price is not always a safe indicator! Check that everything is square, that the pulleys or belts are not lose, that the bed (http://3dprintingforbeginners.com/glossary/bed-2/) is level. Keep it clean. Experience and practice are a must, and you will eventually know enough that something goes wrong by the sound it makes!

When you first get a 3D printer up and running, print out lots of 20mm cubes. It's quite a boring object, but it can help ensure you have a good setup and calibrated machine. You can print these solid to test for over extrusion and size calibration. You can also print hollow to test for accurate perimeter width settings in your slicing program. This will also ensure better and more accurate hole size, model features and improved strength of parts when you have the perimeter width setting and extruder flow rates correctly defined.

Get to know your printer. The beginning is always difficult - test out all the different settings, try printing different shapes with different settings so that you start to understand your printer. At this stage, don't change materials too much as it will blur your results.

Use the force. Join online 3D Print communities to learn from others. Stand on the shoulders of giants to reach even further. This will save you a lot of time and will colour your 3D printing journey.

Get some callipers. They can be purchased on Ebay or Amazon, and are required to accurately measure filament, calibrate your printer, and to adjust your utility - oriented prints for a perfect fit. They really come in handy for measuring stuff that you are trying to model too!

Printing with PLA on blue painters tape is a great starting point. Be sure to wipe down the print bed with an alcohol wipe to remove any grease or grime from the factory before applying the tape.

Getting the perfect extruder height is critical to great prints. I prefer the z-level to be set so that there is a very faint impression left on blue painters tape when removing a PLA model.

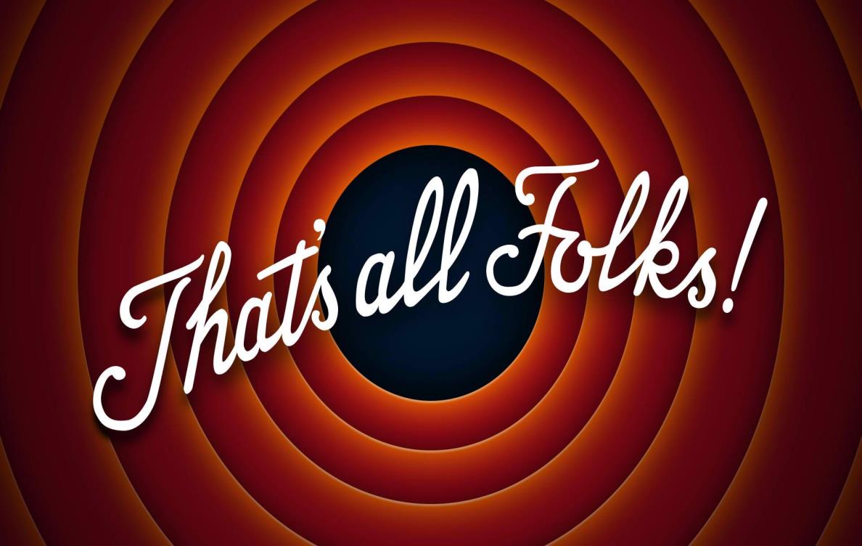
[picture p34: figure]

Anet A8 printer assembly guide for the newbie V0.1

So as the saying goes

I hope you have found this newbie guide useful and it’s given you a better insight into the world of 3D printing and also the fun you can once you have followed a few simple steps.

There is plenty more information out there on the Web and also on the Anet A-series Facebook group page, so if you can’t find what you looking here, I’m sure you will find it out there but just remember one thing when playing “If it isn’t broke don’t fix it”

Thank you.

# K D Smith

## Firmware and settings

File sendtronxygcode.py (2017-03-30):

#! /usr/bin/python
#
# sendtinyboy.py -- most simpilistic gcode forwarder for my 3d printer
#
# (C) 2016 juewei@fabmail.org
# distribute under GPLv2.0 or ask.
#
# 2016-06-23, jw -- initial draught.
# 2016-08-14, jw -- fixed upward move to be really relative.
# 2016-09-05, jw -- better exception handling.
# 2016-10-01, jw -- tested and fixed error handling in ser_readline()
# 2016-10-14, jw -- est_time_min from cura ;TIME: string
#
import sys, re, serial, time
import os.path


verbose=False

ser=None
errorcount=0
def ser_readline():
  global errorcount
  global ser

  try:
    line = ser.readline()
    errorcount=0
  except Exception as e:
    line = ''
    print "ser.readline() error: " + str(e)
    time.sleep(1)
    errorcount += 1
    if errorcount == 5:
      # full re-init: close and open.
      print "ser.readline() re-initializing serial device ..."
      ser.close()
      ser_open()
    if errorcount > 10: 
      raise e
  return line

def ser_open(device=None, baud=115200, timeout=3, writeTimeout=10000):
  global ser

  if device is None:
    devicelist = [ '/dev/ttyUSB0', '/dev/ttyUSB1', '/dev/ttyUSB2', '/dev/ttyUSB3' ]
  else:
    devicelist = [ device ]

  ser = None
  for dev in devicelist:
    try:
      ser = serial.Serial(dev, 115200, timeout=3, writeTimeout=10000)
    except:
      pass
    if ser is not None: break

  if ser is None:
    print("failed to open device: " + str(devicelist))
    sys.exit(0)

  # gobble away initial boiler plate output, if any
  seen = ser_readline()
  if len(seen) == 6 and seen[:4] == 'wait': seen = ''
  while len(seen):
    print "seen: ", seen[:4], len(seen), "xx"
    seen = ser_readline()
    if len(seen) == 6 and seen[:4] == 'wait': seen = ''

def ser_check():
  empty_count = 0
  while True:
    seen = ser_readline()
    if len(seen) == 6 and seen[:4] == 'wait': seen = ''
    if seen[:2] == 'ok':
      if verbose: print seen
      break
    elif seen == '':
      time.sleep(0.1)
      empty_count += 1
      if empty_count > 50:
        break
    else:
      print "check", seen,

def ser_write(line):
  global verbose
  global ser

  if len(line) > 0:
    if verbose: print "out", line
    line += "\n"
    while len(line):
      n = ser.write(line)
      if n < 0: raise WriteError()
      line = line[n:]

## not available on tronxy: M21 says format error:
"""
   	sdcard list [DIR]			; list SDcard contents
   	sdcard delete [DIR/]FILENAME		; 
   	sdcard print [DIR/]FILENAME		; starts a print.
"""

if len(sys.argv) <= 1 or ( sys.argv[1][0] == '-' and sys.argv[1][1] not in "gcf" ):
  print """
Usage
%s [-g|-c|-f] ...

If no option is given, -f is default.

-f FILENAME
    Sends a gcode file to the printer.

-c CMD args ...
   Most commands can be abbreviated to one or two letters. 
   Available commands are:
	up 10mm					; move the printhead up 10mm
	home [all|xy|x|y|z]			; home all or some axis.
	off					; cancel all action and turn motors off.
   	sdcard upload FILENAME [DIR]		; store a file on SDcard

-g CMD args ...
    followed by gcode arguments. E.g. 
	M117 Hello World	; print text on display
	M107			; Fan off
	M106 P0 S127		; Fan 0 speed to 127
	M104 S190		; set extruder temperature to 190 C
        M84			; motors off
	M42 Pxxx Syyy		; set GPIO pin xxx to value yyy.
	G92 X0 Y0 Z0 E0		; define the current positions as origin.
    The full list of supported commands differs per firmware. 
    See http://reprap.org/wiki/G-code
"""
  sys.exit(0)


ser_open()


if sys.argv[1] == '-c':
  if sys.argv[2] in ('u', 'up'):
    ser.write("G21\n");		# ;metric values
    ser.write("G90\n");		# ;absolute positioning
    ser.write("G92 Z0\nG1 Z10.0 F2400\n")	# zero z, then move (relative)
    ser_check()
    print("move up 10mm")
    # ser.write("M109 S190.0\n");		# wait for heat

  elif sys.argv[2] in ('p', 'preheat'):
    ser.write("M104 S190.0\n");		# 190

  elif sys.argv[2] in ('c', 'cool', 'cooldown'):
    ser.write("M104 S0\n");		# cooldown

  elif sys.argv[2] in ('h', 'home'):
    if len(sys.argv) <= 3 or sys.argv[3] in ('all', 'xyz'):
      ser.write("G28 X0 Y0 Z0\n");
    elif sys.argv[3] == 'xy':
      ser.write("G28 X0 Y0\n");
    elif sys.argv[3] == 'x':
      ser.write("G28 X0\n");
    elif sys.argv[3] == 'y':
      ser.write("G28 Y0\n");
    elif sys.argv[3] == 'z':
      ser.write("G28 Z0\n");
    else:
      print "unknown home command. Try all, xy, z."

  elif sys.argv[2] in ('s', 'sdcard'):
    if sys.argv[3] in ('u', 'up', 'upload'):
      ser.write("M21\n")
      print "uploading %s to %s" % (sys.argv[4], "/")
      fd = open(sys.argv[4], 'r')
      ser.write("M28 %s\n" % os.path.basename(sys.argv[4]));
      while True:
        line = fd.readline()
        ser_write(line)
        ser_check()
      ser.write("M29\n")
      
    elif sys.argv[3] in ('d', 'rm', 'del', 'remove', 'delete'):
      print "delete a file from sdcard ..."
      ser.write("M21\n")
      ser.write("M30 %s\n" % (sys.argv[4]))

    elif sys.argv[3] in ('p', 'print'):
      print "start printing a file from sdcard ..."
      ser.write("M21\n")
      ser.write("M23 %s\n" % (sys.argv[4]))
      ser.write("M24\n")

    elif sys.argv[3] in ('stop', 'pause'):
      print "stop printing from sdcard"
      ser.write("M25\n")

    elif sys.argv[3] in ('l', 'ls', 'list', 'dir'):
      print "list files on sdcard"
    else:
      print "unknown sdcard command. Try list, upload, delete, print"
    
  elif sys.argv[2] in ('0', 'o', 'off', 'cancel', 'reset'):
    ser.write("M108\n");
    ser.write("M104 S0\n");
    ser.write("M84\n");

  else:
    print "unkown command, try -h for a list."
    
  ser_check()
  ser.close()
  sys.exit(0)


if sys.argv[1] == '-g':
  # upper case the first word, Mxxx or Gxxx command, keep the rest as they are...
  if sys.argv[2].upper() != sys.argv[2]:
    print "Error: Please use uppercase for G and M commands."
  else:
    line = ' '.join(sys.argv[2:])
    ser_write(line)
    ser_check()
  ser.close()
  sys.exit(0)


file = sys.argv[1]
if file == '-f': file = sys.argv[2]
fd = open(file, 'r')

fd.seek(0,2)	# end
total = fd.tell()
if total == 0: total = 1
fd.seek(0,0)
count = 0
tstamp = time.time()
start_tstamp = tstamp

est_time_min = 0

while True:
  line = fd.readline()
  count += len(line)
  if line == '': break
  m = re.match(';TIME:(\d*)', line)
  if (m):
    est_time_min = int(int(m.group(1))/60.)
    print("Estimated print time: %d min." % est_time_min)
  line = re.sub(';.*', '', line)
  line = re.sub('\s*[\n\r]+$', '', line)
  if line == '': continue

  ser_write(line)

  ser_check()

  now = time.time()
  if (now > tstamp + 10):
    bps = float(count) / (1 + now - start_tstamp) 
    eta = ''
    elapsed = "%d min" % (int((now - start_tstamp)/60))
    if (est_time_min): elapsed += " / %d min" % est_time_min
    if (now > start_tstamp + 2*60):	# start eta calc after 2 min
      secs = int(float(total-count)/bps)
      min = int(secs/60)
      eta = "ETA %d min" % (min)
    print "%.1f %%, %s" % (count * 100. / total, elapsed)
    tstamp = now
    

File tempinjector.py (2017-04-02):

#! /usr/bin/python
#
# tempinjector.py
#
# Original code from: http://www.thingiverse.com/thing:1952380/#files
# Distribute under https://creativecommons.org/licenses/by-nc-sa/3.0/

# 2017-04-02, juergen@fabmail.org    
#  - added G0 and G1 detection.
#  - Z detection also if not first parameter
#  - lowering nozzle detection (to survive initial 15mm jump)
#  - handle nozzle lowering correctly.
#  - added option for an initial offset
#  - added printing of final element height (nice plausibility check of initial offset)
#  - diagnostics show mm, to avoid confusion with layer numbers.

#
import sys

class TempTower():
  def __init__(self):
    pass
  def parse(self, infl, outfl, temp, tstep, hstep, h_off=0.0):
    fi = open(infl, "r")
    try:
      fo = open(outfl, "w")
      try:
        h = hstep + h_off
        wasM104 = False
        started = False
        lastz   = 0
        lastset = 0
        lastzmax = 0
        layerh  = 0
        for l in fi:
          l = l.strip()
          if (len(l) == 0):
            fo.write("\n")
            continue

          cmd = l.split(" ")

          cmd[0] = cmd[0].upper()

          if cmd[0] in ("G0", "G1"):
             for i in range(1, len(cmd)):
               p = cmd[i].upper()
               if len(p) and p[0] in (';', 'Z'):
                 break

             if (p.find("Z") == 0):
                lastz = float(p[1:])
                if lastz > lastzmax:
                  lastzmax = lastz
                if started and (layerh == 0):
                  layerh = lastz
                  print "Layer height detected = ", layerh, "mm, cmd: ", " ".join(cmd)
                if started and (lastz < layerh):
                  layerh = lastz
                  lastzmax = lastz
                  print "Lowering to ", layerh, "mm"

                if started and (lastz >= (h+layerh)):
                  h = h + hstep
                  temp = temp + tstep
                  fo.write("M104 S" + str(temp) + "\n")
                  print "Setting temperature ", temp, "at ", lastz, "mm"
                  lastset = lastz

             if ((p.find("X") == 0) or (p.find("Y") == 0)) and not started:
              started = True

          elif cmd[0] == "M104":
            if not wasM104:
              cmd[1] = "S" + str(temp)   #write new init temp
              print "Initial temperature updated to ", temp
            else:
              print "\tOriginal temp reconfiguration ignored: ", " ".join(cmd)
              cmd = ["; ignored"] + cmd
            wasM104 = True

          elif cmd[0] == "M109":
            cmd[1]  = "S" + str(temp) # update wait for temperature to current
            print "Wait temperature updated to ", temp
            started = True

          else:
            pass # OK other command/comment

          fo.write( " ".join(cmd) + "\n")
      finally:
        fo.write("M104 S0") # for sure :)
        print "\tExtruder off command added: M104 S0"
        print "Height of final element:", lastzmax-lastset, "mm"

        fo.close()
    finally:
      fi.close()

  def help(self):
    print "usage:", sys.argv[0], " input_file.gcode output_file.gcode initial_temp temp_step element_height_mm [start_height_mm]"
    print "\nExample (http://www.thingiverse.com/thing:2184626):"
    print "\t", sys.argv[0], "STX_Better_Temperature_Tower_v5_240-160.gcode STX_TempTow240.gcode 240 -5 7 2.4"
    print "\t", sys.argv[0], "STX_Better_Temperature_Tower_v5_200-160.gcode STX_TempTow200.gcode 200 -5 7 2.4"


if __name__ == "__main__":
  tt = TempTower()
  if len(sys.argv) == 6:
    tt.parse(sys.argv[1], sys.argv[2], int(sys.argv[3]), int(sys.argv[4]), float(sys.argv[5]))
    print "Done"
  elif len(sys.argv) == 7:
    tt.parse(sys.argv[1], sys.argv[2], int(sys.argv[3]), int(sys.argv[4]), float(sys.argv[5]), float(sys.argv[6]))
  else:
    tt.help()

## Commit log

2017-03-12 assembly HOWTO.txt and some custom parts...
    [display-spacer.fcstd, display-spacer.stl, y-idler-mount.fcstd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]
2017-03-12 less tension, added clearances. Curved front face.
    [y-idler-mount.fcstd, y-idler-mount.stl]
2017-03-12 longer space for screw. bit more tenision.
    [y-idler-mount.fcstd, y-idler-mount.stl]
2017-03-12 several parts re-done.
    [end-cap.fcstd, end-cap.stl, y-endstop-mount.scad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]
2017-03-12 maximising with modded parts...
    [display-spacer.fcstd, display-spacer.stl]
2017-03-12 made y-endstop-mount more solid in the front.
    [y-endstop-mount.scad, y-endstop-mount.stl]
2017-03-12 end stop pitch is 10mm, not 9mm.
    [y-endstop-mount.scad, y-endstop-mount.stl]
2017-03-13 rotated y-motor. added x-gantry cover to keep rods inside the end piece even if belt is tensioned.
    [x-gantry-far-end-cover.scad, x-gantry-far-end-cover.stl]
2017-03-13 adjusting fit of x-gantry-far-end-cover
    [x-gantry-far-end-cover.scad, x-gantry-far-end-cover.stl]
2017-03-16 155mm x 160mm is the maxed out size for the print bed.
    This requires:
    - lowered y-idler
    - belt connctor moved inwards by 8mm on the table
    - x-endstop moved right by 4mm-7mm (adjustable slots on the print head)
    - smal cut outs at the frame.
    - y-motor rotated so that the connector is out of the way.
    - y-rods end caps modded, so that short 10mm screws can be used.
2017-03-20 added stl files of the bigger build plate, hacked together with inkscape and freecad.
    [plate.fcstd, tronxy-plate-fc.stl, tronxy-plate.stl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]
2017-03-26 first working draft for testing gcode commands. Note that the asynchronous reader is completely broken. Most of the time we get stuck in a "Resend" loop.
    [sendtronxygcode.py]
2017-03-30 added cura-2.4 settings for my tronxy.
    [Tronxy-xy100.stack.cfg]
2017-04-01 raft fixed to peel of much easier.
    [Tinyboy+Fabricator.stack.cfg, Tronxy-xy100.stack.cfg]
2017-04-02 Experimental ABS settings added.
    [Tronxy-xy100.stack.cfg]
2017-04-02 tempinjector.py from http://www.thingiverse.com/thing:1952380 - handle nozzle lowering correctly. - added option for an initial offset - added printing of final element height (nice plausibility chec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
    [tempinjector.py]
2017-04-02 - handle both G0, G1 - Z detection also if not first parameter - added printing of final element height (nice plausibility check of initial offset) - diagnostics show mm, to avoid confusion with laye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
    [tempinjector.py]
2017-04-16 ZZREADME added.
    [Tinyboy+Fabricator.stack.cfg, Tronxy-xy100.stack.cfg]
2017-04-16 added files from https://www.imakr.com/en/forum/topic/42-startt-3d-printed-part-files
    [Left.stl, Right.stl]
2017-04-17 The printer firmware chokes on empty commands. cura240-no-empty-cmd.patch avoids that.
2017-04-17 So strange: When checksumming is on, we see many erratic movemements along the Y axis. Also the printer slows down and runs the extruder looon ways back an dforth. This takes significant time. When c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
    When the extrueder is off, no slow down is seen.
    (also no slow down for erratic filament movement, but hey, the extuder
    is off...) This probably does not mean anything then.....
2017-05-04 Added Fan Duct Part.
    [StarttFanDuct.skp, StarttFanDuct.stl]
2017-08-12 scanned all the lasercut 5mm parts
2017-08-13 Vectorized them all to a 0.5mm grid.
2017-08-22 print head parts scanned.
    [plate.fcstd, tronxy-plate-fc.stl]
2017-08-22 added parts from the print head
2017-08-29 10mm gained in x direction!
2017-08-31 extruder head centerplate added.
2017-11-06 recreated the original head...
    [head.fcstd]
2017-11-08 4 pieces modified, so that the head moves up 25mm.
    [head.fcstd]
2017-11-09 move Z endstop by 25mm too.
2017-11-10 23mm is better.
2017-11-23 moved the head 2mm away from the back plate.
2019-06-14 extruder diameter addedd
